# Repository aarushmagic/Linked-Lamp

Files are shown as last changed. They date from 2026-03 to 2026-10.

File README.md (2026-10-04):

<p align="center">
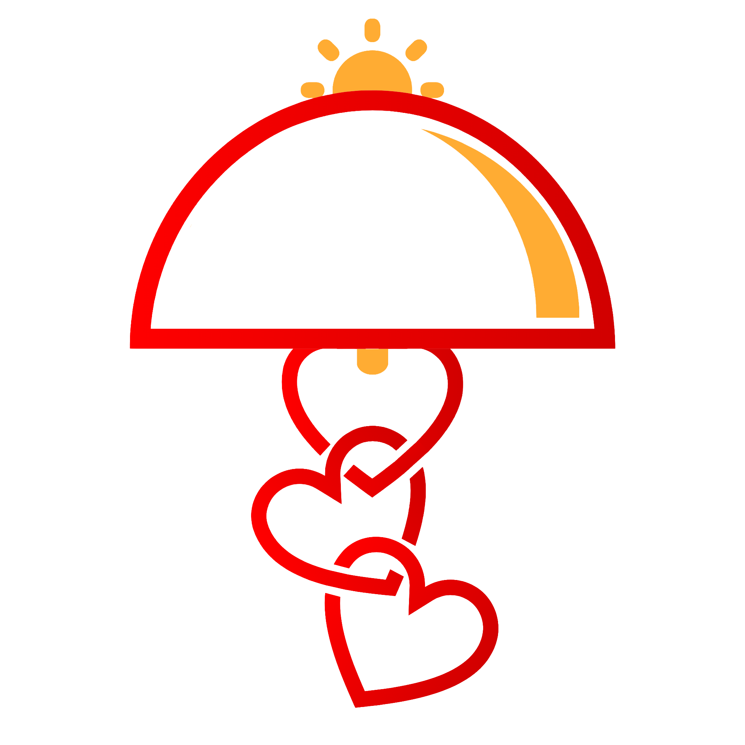
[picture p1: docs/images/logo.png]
Linked Lamp
  
</p>

<h1 align="center">Linked Lamp</h1>

<p align="center">
  An open-source Wi-Fi connected <strong>Friendship Lamp</strong>.<br>
  Tap your lamp to let someone know you're thinking of them — their lamp lights up in your chosen color, anywhere in the world. 
</p>

<p align="center">
  <a href="https://linkedlamp.com">Website</a> · <a href="https://linkedlamp.com/setup.html">Setup Guide</a> · <a href="https://linkedlamp.com/faq.html">FAQ</a>
</p>

---

## ✨ Features

- **Touch Gestures** — Tap to send, double-tap to turn off, hold to pick a new color
- **Breathing Glow** — 20-second pulsing animation (sine wave, ~2s cycle) when a signal arrives, then steady light
- **Smooth Color Transitions** — 5-second gradual fade from current color to new color on every signal
- **Send Confirmation Flash** — Single tap briefly flashes your sent color for 1 second, then reverts
- **Color Pick Confirmation** — After hold-release color selection, lamp flashes the picked color for 3 seconds
- **Color Cycle Presets** — Send multi-color animated sequences from the web app with configurable hold and transition times
- **Virtual Bonfire Mode** — Share a synchronized, organic flickering campfire with your partner from the web app, stoked by adding logs
- **Customizable** — Set your default color, lamp-on duration (1–30 min), and max brightness
- **Nighttime Mode** — Schedule quiet hours with timezone-aware NTP-based timing; reduce brightness or keep the lamp fully off
- **Web App** — Send signals, manage presets, adjust settings, and check for updates from your phone
- **Preset Signals** — Quick-send "I Love You", "I Miss You", or custom messages
- **Ambient Mode** — Optional low-power glow (10% of daytime brightness) in your chosen color or animated effect when the lamp is inactive
- **OTA Updates** — Firmware updates pushed wirelessly with automatic rollback protection (firmware is only marked valid after MQTT connects)
- **Multi-Broker Support** — Works with EMQX, HiveMQ, Eclipse Mosquitto, and any TLS-capable MQTT broker
- **Resilient Connectivity** — Auto-reconnects WiFi and MQTT; reboots after 5 minutes of WiFi failure; retries MQTT every 5 seconds with escalating recovery strategies

## 🔧 Hardware Options

You'll need an **ESP32-WROOM** dev board, a **TTP223** touch sensor, and a 3D-printed enclosure. Then choose one of two lighting methods:

| | PCB | NeoPixel |
|---|---|---|
| **Light Source** | 6× Common Anode RGB LEDs on a custom PCB | WS2812B NeoPixel Ring (up to 16 LEDs, 66mm) |
| **Soldering** | Through-hole components onto PCB | 3 wires to the ESP32 |
| **Brightness** | Standard | Slightly brighter |

Both options produce nearly identical lamps. Any Linked Lamp can connect to any other Linked Lamp regardless of which method was used.

### Wiring

| Signal | GPIO |
|---|---|
| Touch Sensor (TTP223 IO) | 4 |
| **PCB** — Red / Green / Blue channels | 13 / 14 / 27 |
| **NeoPixel** — Data IN | 27 |

Schematics and PCB Gerber files are in `Circuit/`. 3D-printable enclosure files are in `3D Models/`.

## 🚀 Setup

### Browser-Based Setup (Recommended)

The [Setup Guide](https://linkedlamp.com/setup.html) walks you through the entire process:

1. **Parts** — Choose PCB or NeoPixel, download 3D files, and gather components
2. **Assembly** — Solder, wire, and assemble the lamp (takes less than 30 minutes)
3. **Software** — Flash firmware from your browser (Chrome/Edge) or via PlatformIO

### PlatformIO (Advanced)

For developers who want to modify the firmware or use a custom MQTT broker:

1. Install [VS Code](https://code.visualstudio.com/) + [PlatformIO](https://platformio.org/)
2. Open `firmware/pcb/` or `firmware/neopixel/` depending on your hardware
3. Copy `data/config.example.json` → `data/config.json` and fill in your details:
   ```json
   {
     "device_id": "A",
     "mqtt_server": "your-broker.someMQTTBroker.com",
     "mqtt_port": 8883,
     "mqtt_user": "your_username",
     "mqtt_pass": "your_password",
     "delimeter": "/",
     "ota_url": "https://www.linkedlamp.com",
     "owner_name": "Your Name"
   }
   ```
   Set `device_id` to `"A"` for the first lamp and `"B"` for the second. Use the same broker credentials for both.
4. **Upload Filesystem Image** (PlatformIO sidebar → esp32dev → Platform) to push config
5. **Upload** (→ arrow in the bottom bar) to flash firmware
6. Repeat for the second lamp with `device_id` set to `"B"`

### First Boot

On first power-up, the lamp creates a Wi-Fi network called **"Linked Lamp Setup"**. Connect from your phone, select your home network, and enter the password. The lamp will remember it across restarts.

### Web App

The Setup Guide generates personalized Web App UIDs for each lamp. Each person gets a unique token that connects them to the right lamp. You may also choose to save the website as a progressive web app (PWA) on your phone for easier access.
```
https://www.linkedlamp.com/my
```

After the first visit, credentials are saved — you can just open the page normally.

## 📱 How to Use

| Action | What Happens |
|---|---|
| **Single Tap** | Sends your default color to the other lamp. Flashes the sent color for 1 second as confirmation. |
| **Double Tap** | Turns off your lamp (if it's on). If Virtual Bonfire mode is active, extinguishes the fire for both lamps. |
| **5+ Taps** | Resets WiFi settings (only works when lamp is off). Flashes red before restarting. |
| **Hold 1.5s+** | Cycles through all colors (~6 seconds per full rotation). Lift your finger to pick — the lamp flashes your selection for 3 seconds, then saves it as your new default. |

## 🔄 Pushing OTA Firmware Updates (For Maintainers)

1. Compile in PlatformIO — binary outputs to `firmware/[type]/.pio/build/esp32dev/firmware.bin`
2. Run `python docs/flash/build_template.py` to copy binaries
3. Commit and push to GitHub — GitHub Pages hosts the update files
4. Users can trigger an update on-demand by tapping "Check for Update" in the web app.

The ESP32 automatically rolls back if new firmware crashes before reaching `setup()`.

## 📜 License

GNU General Public License v3.0 — see [LICENSE](https://www.gnu.org/licenses/gpl-3.0.html).

## 🙏 Credits

[WiFiManager](https://github.com/tzapu/WiFiManager) · [PubSubClient](https://github.com/knolleary/pubsubclient) · [ArduinoJson](https://github.com/bblanchon/ArduinoJson) · [iro.js](https://iro.js.org/) · [MQTT.js](https://github.com/mqttjs/MQTT.js) · [esptool-js](https://github.com/espressif/esptool-js)

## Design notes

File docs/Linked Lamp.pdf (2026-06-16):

# First Time Setup

1.Plug in the lamp using a USB-C cable and a 5V power adapter
2.Connect your phone to the "Linked Lamp Setup" WiFi network.
3.A configuration page will open automatically. If not, go to http://192.168.4.1 in a browser. 4.Select your home Wi-Fi network, enter the password, and tap Save. The lamp will restart and blink twice to indicate it is connected to WiFI. a.Note: Only 2.4GHz WiFi networks are supported
5.Open the Linked Lamp Dashboard (www.linkedlamp.com/my) and enter your Unique ID (UID) found at the end of this manual
6.If prompted, follow the on-screen steps to install the dashboard as a Progressive Web App (PWA) for ease of use.

# Using the Lamp

1.Single Tap: Sends your color to your partner’s lamp (your lamp will flash briefly to confirm).
2.Tap & Hold: Cycles through colors. Release at any color to save it as your new default.
3.Double Tap: Turns the lamp off (does not affect ambient mode light).
4.Quickly Tap 5+ Times: Resets Wi-Fi settings (confirmed by two red flashes). Then repeat setup steps 2–4.

# LED Indicators

Double green flash: WiFi connected successfully. Double red flash: WiFi credentials are being reset (triggered by 5+ taps). The lamp restarts with the setup hotspot.
1-second color flash: Send confirmation. After a single tap, the lamp briefly shows the color you sent 3-second color flash: Color pick confirmation. After holding to select a new default color, the lamp shows your selection for 3 seconds.
20-second breathing pulse: Signal received. The lamp gently pulses for 20 seconds, then holds a steady glow until the timer expires.

# Firmware Updates

Check for updates manually in the dashboard under Settings > Check for Update. The lamp does not check for or install updates automatically.

Updates are downloaded over Wi-Fi and applied automatically, after which the lamp will reboot.

While automatic crash-recovery is built-in, updates are not guaranteed to be bug-free. Review the source code at www.github.com/aarushmagic/Linked-Lamp before updating.

# My Dashboard

The Web App dashboard is your remote control. Open it in any browser at www.linkedlamp.com/my. Once you enter your Unique ID (UID), your lamp is linked!

# Send Tab

View online/offline status in the top-right corner. Click the icon for details on each individual lamp. Press

"Send Signal" to send your default color to your partner.
“Signal Sending

"
means the signal has left your device.
"Signal Sent"
means the partner

'

s lamp has
received the signal and turned on. Create

"Quick Signals

" (presets) using a single color or a custom color cycle of up to 10 colors.
View the timestamp of the last signal received from your partner.

# Settings Tab

My Default Color: Pick the color sent to your partner when you physically tap the lamp or send tap using the dashboard.
Daytime: Customize the lamp

'

s behavior during
normal hours.
Lamp On Time: Adjust how long your lamp stays lit upon receiving a tap
Max Brightness: Set the daytime light intensity

Ambient Mode: Toggle a low-power background glow in your choice of color when the lamp is idle. Nighttime Mode: Enable a customized schedule to change the lamp

'

s behavior during quiet hours. Schedule & Timezone: Choose your timezone and set the night start/end times.
Night Behavior: Adjust the lamp-on duration and lower the brightness (set to 0% to keep the lamp completely off).
Note: Ambient lighting automatically turns off when Nighttime mode is active.
Check for Update: Manually check for and install the latest wireless firmware updates.
Switch Accounts: Link and switch between multiple lamp profiles on the same device.
Available only when installed as an app/PWA To add multiple accounts, select “Switch Accounts

” in the dashboard and type in the UID of the new lamp.

# Secondary Lamp

Each user is allowed to add one secondary lamp to their account. Visit www.linkedlamp.com/setup-software and simply flash a new lamp using the exact same configurations as your original. The new lamp will automatically detect the primary device and register itself as secondary. Once linked, both lamps will receive incoming signals in sync, and tapping either lamp will send a signal to your partner.

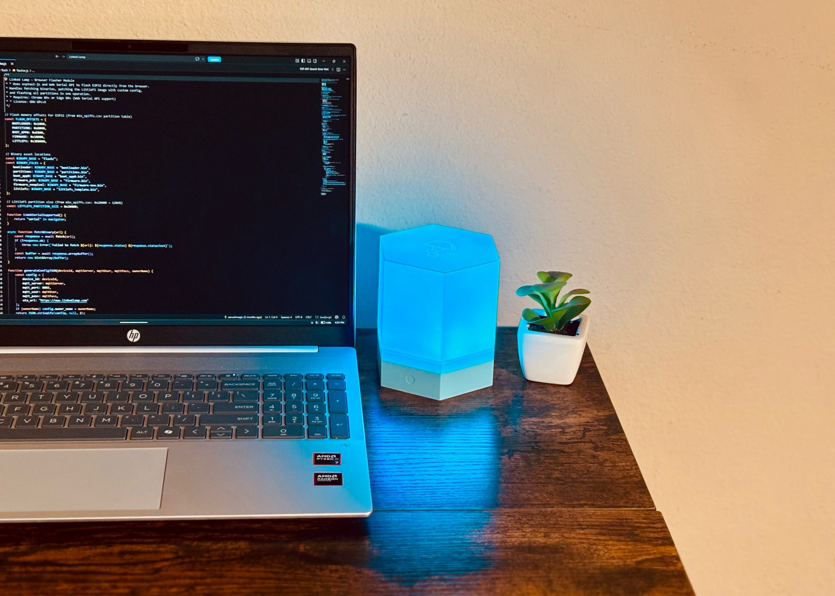
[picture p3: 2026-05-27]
docs/images/blue_lamp.jpg

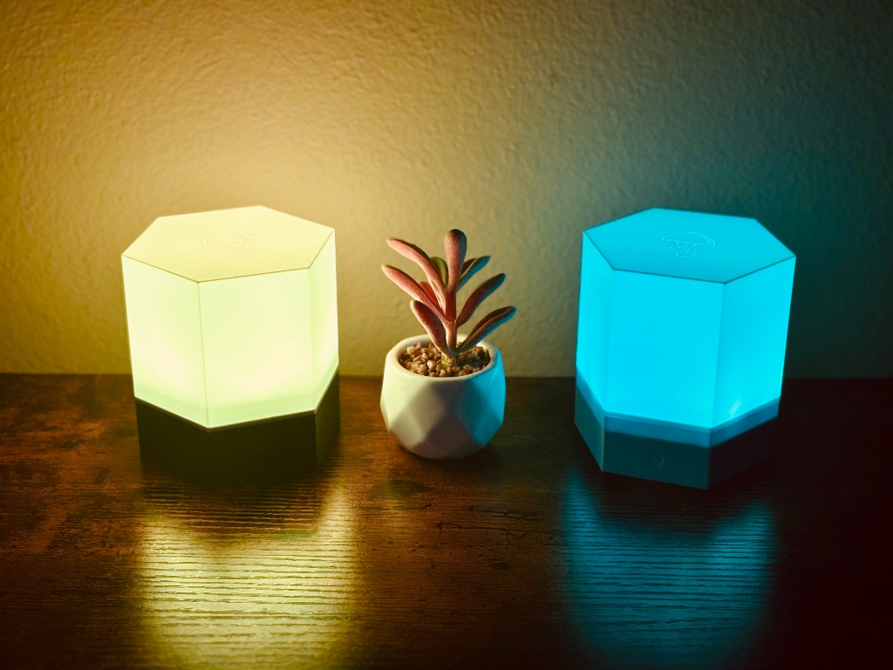
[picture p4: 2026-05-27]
docs/images/lamps_hero.jpg

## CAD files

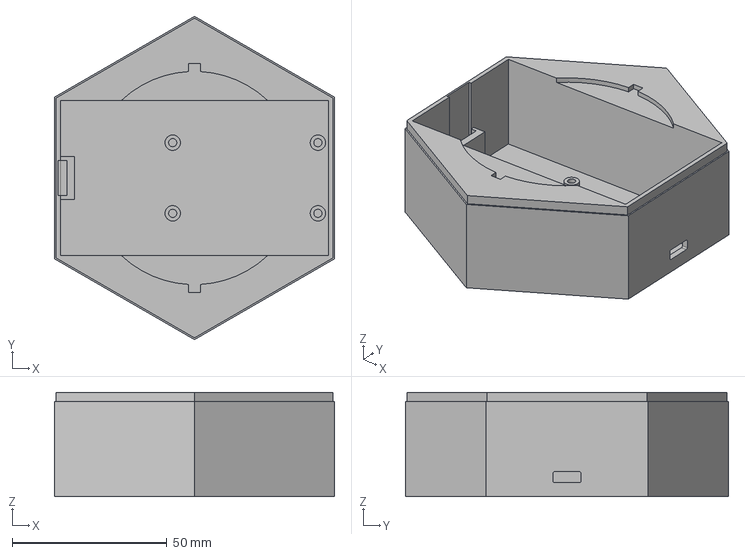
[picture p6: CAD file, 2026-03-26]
3D Models/Neopixel Lamp - 67mm Ring/Neopixel Lamp - Base (M2.5).step
90.6 x 104.6 x 33.8 mm

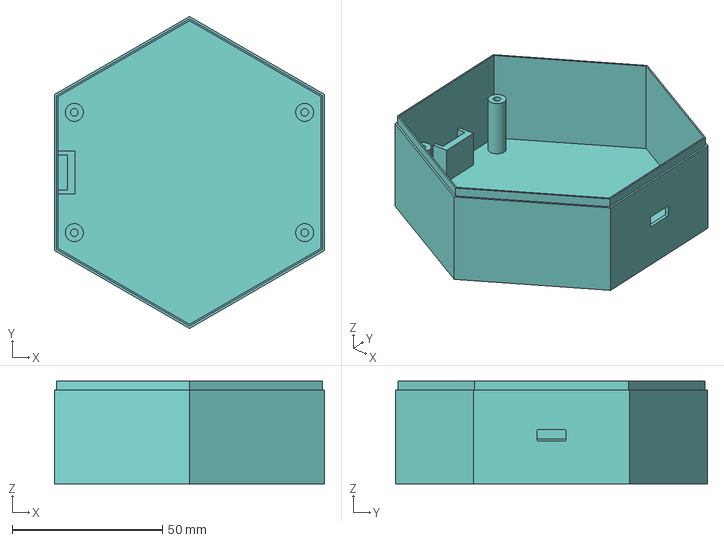
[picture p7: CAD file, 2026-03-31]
3D Models/PCB Lamp - 100mm Hexagon/PCB Lamp 100mm - Base (M2.5).step
89.9 x 103.8 x 34.2 mm

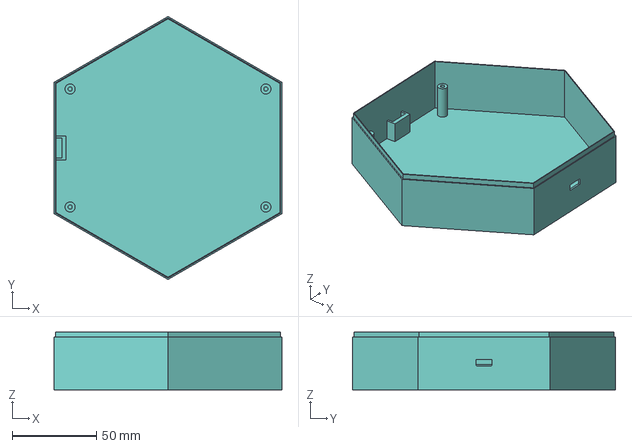
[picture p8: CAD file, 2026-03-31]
3D Models/PCB Lamp - 6in Hexagon/PCB Lamp 6in - Base (M2.5).step
134.8 x 155.7 x 34.2 mm

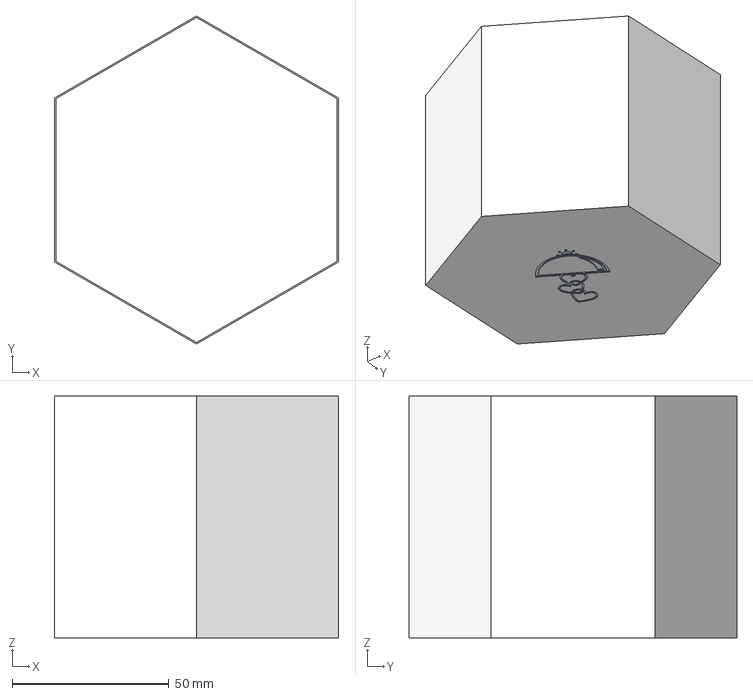
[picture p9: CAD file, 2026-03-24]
3D Models/Neopixel Lamp - 67mm Ring/Neopixel Lamp - 3in Diffuser.step
90.6 x 104.6 x 77.2 mm

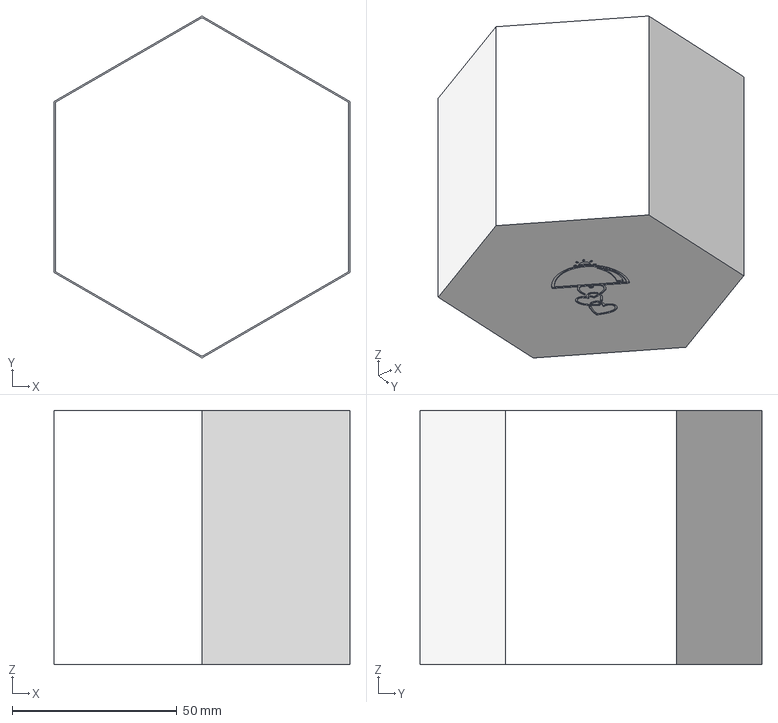
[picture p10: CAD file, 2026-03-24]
3D Models/PCB Lamp - 100mm Hexagon/PCB Lamp 100mm - 3in Diffuser.step
89.8 x 103.7 x 77.2 mm

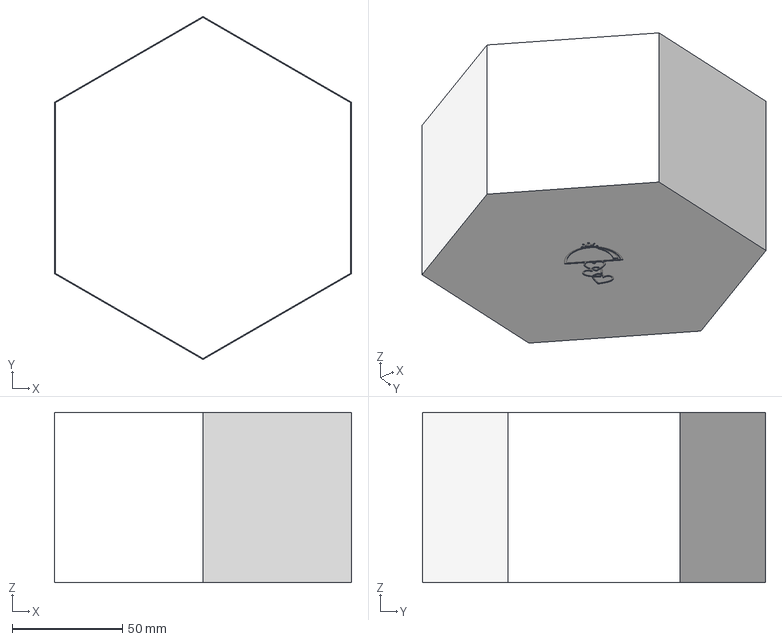
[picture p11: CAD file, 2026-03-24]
3D Models/PCB Lamp - 6in Hexagon/PCB Lamp 6in - 3in Diffuser.step
134.8 x 155.7 x 77.2 mm

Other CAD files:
3D Models/Neopixel Lamp - 67mm Ring/Neopixel Lamp - Base (Spokes).step

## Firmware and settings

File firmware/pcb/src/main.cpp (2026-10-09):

/**
 * Linked Lamp Firmware - Transistor / PCB Version
 * 
 * Controls an ESP32-based friendship lamp using discrete NPN transistors
 * to drive 7 common anode RGB LEDs, a TTP223 touch sensor, and MQTT sync.
 * 
 * Core Hardware:
 *   - ESP32-WROOM
 *   - TTP223 Touch Sensor (Active HIGH, Pin 4)
 *   - 3 NPN Transistors driving common anode RGB LEDs (Pins 13, 14, 27)
 * 
 * Core Features:
 *   - Non-blocking MQTT communication via WebSockets
 *   - Capacitive touch state machine (single tap to send, double tap to turn off, hold to cycle colors)
 *   - Dual-core execution (main loop on Core 1, serial command listener on Core 0)
 *   - Ambient lighting (solid or animated) and timezone-aware nighttime modes
 *   - Over-the-Air (OTA) self-updates with rollback protection
 * 
 * License: GNU GPLv3
 */

#include <Arduino.h>
#include <WiFi.h>
#include <WiFiManager.h>
#include <PubSubClient.h>
#include <HTTPClient.h>
#include <WiFiClientSecure.h>
#include <Update.h>
#include <LittleFS.h>
#include <ArduinoJson.h>
#include <lwip/dns.h>
#include <esp_ota_ops.h>
#include <time.h>
#include "version.h"

// =============================================================================
// Hardware Type Definition
// =============================================================================
#define HW_TYPE "pcb"

// =============================================================================
// Pin Definitions
// =============================================================================
#define TOUCH_SENSOR_PIN 4   // Touch sensor input (Active HIGH)
#define RED_PWM_PIN      13  // Red LED channel PWM pin
#define GREEN_PWM_PIN    14  // Green LED channel PWM pin
#define BLUE_PWM_PIN     27  // Blue LED channel PWM pin

// =============================================================================
// Config values persisted in LittleFS
// =============================================================================
String device_id      = "A";
String target_id      = "B";
String mqtt_server    = "";
int    mqtt_port      = 8883;
String mqtt_user      = "";
String mqtt_pass      = "";
String mqtt_delimiter = "/";
String ota_url        = "https://www.linkedlamp.com";  // Base URL for authorized OTA firmware check
String owner_name     = "";  // Device owner name

// Device role for status mapping
String role = "";
bool   isSupplementary = false;
volatile bool isRebooting = false;
volatile bool pauseCore1 = false;

// Epoch timestamp of the last tap
unsigned long lastTapTimestamp = 0;
bool isFirmwareUpdated = false;

// =============================================================================
// Web-synced settings persisted in LittleFS
// =============================================================================
String defaultColor          = "#FF0000";
int    lampOnTimeMinutes     = 5;       // Day mode active duration (min)
int    dayMaxBrightness      = 255;     // 0-255
bool   nightModeEnabled      = false;
String nightStartTime        = "22:00";
String nightEndTime          = "08:00";
int    nightLampOnTimeMinutes = 5;
int    nightMaxBrightness    = 128;
String userTimezone          = "EST5EDT"; // POSIX timezone format
bool   ambientModeEnabled    = false;
String ambientColor          = "#0000FF";

// =============================================================================
// Ambient Lighting Modes
// =============================================================================
enum AmbientEffect {
  AMBIENT_SOLID,
  AMBIENT_FIRE,
  AMBIENT_BREATH,
  AMBIENT_LAVA,
  AMBIENT_RAIN,
  AMBIENT_AURORA
};
AmbientEffect currentAmbientEffect = AMBIENT_SOLID;

// Cached parsed solid color
uint8_t ambSolidR = 0, ambSolidG = 0, ambSolidB = 255;

// Last calculated ambient output (normalized linear, brightness applied, before gamma)
// Used as the starting point for cross-fading when an active signal arrives
float lastAmbOutR = 0.0f, lastAmbOutG = 0.0f, lastAmbOutB = 0.0f;

// Volatile animation state (kept strictly in RAM, never committed to flash)
unsigned long lastAmbientFrameMs = 0;
float         breathPhase        = 0.0f;
unsigned long nextRainFlareMs    = 0;
unsigned long rainFlareStartMs   = 0;
const unsigned long AMBIENT_FRAME_MS = 20; // ~50 fps update rate

// =============================================================================
// Application state and timing trackers
// =============================================================================
bool           isLampOn           = false;
unsigned long  lampOnStartTime    = 0;
unsigned long  lampDurationMs     = 300000UL; // Day mode active duration in ms
bool           isPulsing          = false;
unsigned long  pulseStartTime     = 0;
const unsigned long PULSE_DURATION_MS = 20000; // Pulse duration in ms

// Pre-scaled output color state
uint8_t currentR = 0, currentG = 0, currentB = 0;
int     currentMaxBrightness = 255;

// Hardware LEDC PWM configuration
const int redChannel    = 0;
const int greenChannel  = 1;
const int blueChannel   = 2;
const int pwmFreq       = 5000;
const int pwmResolution = 13;
const uint32_t PWM_MAX  = 8191; // 2^13 - 1

// Display Color Profile: Standard sRGB Transfer Function (IEC 61966-2-1)
// Calibrated to match the perceptual color curve of iOS and Android phone screens
inline float srgbToLinear(float c) {
  if (c <= 0.0001f) return 0.0f;
  if (c >= 1.0f)    return 1.0f;
  if (c <= 0.04045f) {
    return c / 12.92f;
  }
  return powf((c + 0.055f) / 1.055f, 2.4f);
}

// Ambient mode intensity ratio (calibrated ~4-5% dimmer to achieve subtle background glow)
const float AMBIENT_RATIO = 0.35f;

// Breathing pulse modulation: balanced 50% to 100% perceived brightness
const float PULSE_MIN_FACTOR = 0.50f;
const float PULSE_DEPTH      = 0.50f;

// Hardware PWM Helper (Compatible with ESP32 Arduino Core 2.x and 3.x)
#if defined(ESP_ARDUINO_VERSION_MAJOR) && (ESP_ARDUINO_VERSION_MAJOR >= 3)
  inline void initPwmPin(uint8_t pin, uint32_t freq, uint8_t resolution, uint8_t channel) {
    ledcAttachChannel(pin, freq, resolution, channel);
  }
  inline void writePwmDuty(uint8_t pin, uint8_t channel, uint32_t duty) {
    ledcWrite(pin, duty);
  }
#else
  inline void initPwmPin(uint8_t pin, uint32_t freq, uint8_t resolution, uint8_t channel) {
    ledcSetup(channel, freq, resolution);
    ledcAttachPin(pin, channel);
  }
  inline void writePwmDuty(uint8_t pin, uint8_t channel, uint32_t duty) {
    ledcWrite(channel, duty);
  }
#endif

// Touch sensor gesture state machine
unsigned long lastTouchTime     = 0;
unsigned long touchStartTime    = 0;
int           tapCount          = 0;
bool          isTouching        = false;
bool          wasTouching       = false;
const unsigned long TAP_TIMEOUT = 400; // Multi-tap window (ms)
bool          longPressTriggered = false;

// Color wheel spectrum cycle state
float hue              = 0.0;
bool  isCyclingColors  = false;
unsigned long cycleStartTimeMs = 0;
float cycleStartHue = 0.0;
const float CYCLE_PERIOD_MS = 6000.0; // Color cycle period (ms)

// Color transition crossfade state
bool isTransitioning = false;
unsigned long transitionStartMs = 0;
const unsigned long TRANSITION_DURATION = 5000; // Transition duration (ms)
uint8_t transFromR = 0, transFromG = 0, transFromB = 0;
uint8_t transToR = 0, transToG = 0, transToB = 0;

// Custom multi-color pattern cycle state
struct CycleEntry {
  uint8_t r, g, b;
  unsigned long holdMs;
  unsigned long transMs;
};
const int MAX_CYCLE_ENTRIES = 50;
CycleEntry cycleEntries[MAX_CYCLE_ENTRIES];
int cycleEntryCount = 0;
int cycleCurrentIndex = 0;
bool isColorCycling = false;
unsigned long cycleStepStartMs = 0;
enum CyclePhase { CYCLE_HOLD, CYCLE_TRANSITION };
CyclePhase cyclePhase = CYCLE_HOLD;

// Feedback flash state for tap transmissions
bool isSendFlashing = false;
unsigned long sendFlashStart = 0;
const unsigned long SEND_FLASH_DURATION = 1000; // Confirmation flash duration (ms)
uint8_t preSendR = 0, preSendG = 0, preSendB = 0;
bool wasLampOnBeforeSend = false;

// Feedback flash state for color selection
bool isColorPickFlashing = false;
unsigned long colorPickFlashStart = 0;
const unsigned long COLOR_PICK_FLASH_DURATION = 3000; // Pick confirmation flash duration (ms)
uint8_t prePickR = 0, prePickG = 0, prePickB = 0;
bool wasLampOnBeforePick = false;

// =============================================================================
// WiFi networking state
// =============================================================================
WiFiManager     wifiManager;
WiFiClientSecure espClientSecure;
PubSubClient    mqttClient(espClientSecure);

bool           wifiConnected            = false;
bool           hasConnectedOnce         = false;
unsigned long  lastWifiReconnectAttempt  = 0;
const unsigned long WIFI_RECONNECT_INTERVAL = 15000;
unsigned long  wifiDisconnectedSince    = 0;
const unsigned long WIFI_RESTART_TIMEOUT  = 300000; // Reboot threshold (ms) on connection loss

// Persistent RTC memory (survives soft resets)
RTC_NOINIT_ATTR uint32_t rtcBootMarker;
RTC_NOINIT_ATTR bool rtcLastKnownIsNight;
RTC_NOINIT_ATTR bool rtcBonfireActive;
RTC_NOINIT_ATTR uint64_t rtcLastBonfireLogEpoch;
const uint32_t BOOT_MARKER_VALUE = 0xCAFEBEEF;
bool isColdBoot = false;

// =============================================================================
// Virtual Bonfire State (Co-Presence Glow) - Zero Flash Writes
// =============================================================================
bool          isBonfireActive     = false;
uint64_t      lastBonfireLogEpoch = 0;
uint64_t      flareStartEpoch     = 0;
bool          isBonfireFlaring    = false;

// MQTT connection state
unsigned long  lastMqttReconnectAttempt = 0;
const unsigned long MQTT_RECONNECT_INTERVAL = 5000;
int            mqttFailCount = 0;

// Periodic status maintenance
unsigned long  lastStatusCheck = 0;
const unsigned long STATUS_CHECK_INTERVAL = 300000; // 5 minutes
bool           selfStatusOnline = false; // Tracks reported online status

// Retained MQTT state refresher
unsigned long lastDailyRefresh = 0;
const unsigned long DAILY_REFRESH_INTERVAL = 86400000UL; // Daily refresh interval (ms)

// Dynamically generated MQTT topics
String triggerTopicSub;
String triggerTopicPub;
String settingsTopicSub;
String statusTopicPub;
String partnerStatusTopicSub;    // Subscribes to partner primary status
String partnerSupStatusTopicSub; // Subscribes to partner secondary status
String bonfireTopicSub;          // Retained bonfire state topic
String bonfireTopicPub;          // Partner bonfire state topic

// =============================================================================
// Function Prototypes
// =============================================================================
void loadConfig();
void loadState();
void saveState();
void setupPins();
void setupMQTT();
void onWifiConnect();
void handleWifi();
void handleMqttReconnect();
void handleTouch();
void doActionBasedOnTaps();
void handleLEDs();
void mqttCallback(char* topic, byte* payload, unsigned int length);
void parseSettings(String payload);
void setColor(String hexColor);
void setRGB(uint8_t r, uint8_t g, uint8_t b);
void setRGBFloat(float rLin, float gLin, float bLin);
void setRGBDuty(uint32_t dutyR, uint32_t dutyG, uint32_t dutyB);
uint32_t applyGamma13(float linearIntensity);
bool isAuthorizedOTAUrl(const String& urlStr);
void performOTA(String url);
float hexToHue(String hexColor);
bool isNighttime();
void publishSettingsViaMQTT();
void startColorTransition(uint8_t toR, uint8_t toG, uint8_t toB);
void parseColorCycle(String payload);
void serialCommandTask(void *pvParameters);
void processSerialCommand(String cmd);
void detectRole();
uint64_t getEpochMs();
void startBonfire(uint64_t logEpoch, bool publishMqtt);
void addBonfireLog(bool publishMqtt);
void extinguishBonfire(bool publishMqtt, const char* reason);
void renderBonfireFrame(uint64_t epochMs);
void resolveAmbientEffect();
void renderAmbientFrame();
void writeAmbientOutput(float rLin, float gLin, float bLin);
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
void loop() {
  if (pauseCore1) { delay(10); return; }
  if (isRebooting) return;
  wifiManager.process();
  handleWifi();
  handleTouch();
  handleLEDs();
}

// =============================================================================
// WiFi Networking and Maintenance
// =============================================================================
void onWifiConnect() {
  wifiConnected = true;
  mqttFailCount = 0;

  Serial.println("WiFi Connected!");
  Serial.print("IP Address: ");
  Serial.println(WiFi.localIP());

  // Override default DNS with public servers
  ip_addr_t dns1, dns2;
  IP4_ADDR(&dns1.u_addr.ip4, 8, 8, 8, 8);
  dns1.type = IPADDR_TYPE_V4;
  IP4_ADDR(&dns2.u_addr.ip4, 1, 1, 1, 1);
  dns2.type = IPADDR_TYPE_V4;
  dns_setserver(0, &dns1);
  dns_setserver(1, &dns2);
  Serial.println("Public DNS set: 8.8.8.8 / 1.1.1.1");

  // Pulse green to confirm local connection
  if (!hasConnectedOnce && isColdBoot) {
    hasConnectedOnce = true;
    
    setRGB(0, 120, 0);
    delay(200);
    setRGB(0, 0, 0);
    delay(200);
    setRGB(0, 0, 0);
    delay(200);
    setRGB(0, 120, 0);
    delay(200);
    setRGB(0, 0, 0);
  }

  // Sync time against configured timezone
  configTzTime(userTimezone.c_str(), "pool.ntp.org", "time.nist.gov", "time.google.com");
}

void handleWifi() {
  if (WiFi.status() == WL_CONNECTED) {
    if (!wifiConnected) {
      onWifiConnect();
    }

    // Maintain non-blocking MQTT client state
    if (!mqttClient.connected()) {
      handleMqttReconnect();
    } else {
      mqttClient.loop();

      // Correct reported status if retained state is inconsistent
      if (millis() - lastStatusCheck >= STATUS_CHECK_INTERVAL) {
        lastStatusCheck = millis();
        if (!selfStatusOnline) {
          String onlineMsg = String("ONLINE:") + HW_TYPE;
          mqttClient.publish(statusTopicPub.c_str(), onlineMsg.c_str(), true);
          Serial.println("Status correction: re-published ONLINE (was showing OFFLINE)");
        }
      }

      // Retained MQTT state refresher: Constantly refresh retained messages just in case the broker drops them
      if (millis() - lastDailyRefresh >= DAILY_REFRESH_INTERVAL) {
        lastDailyRefresh = millis();
        
        // Push Status
        String onlineMsg = String("ONLINE:") + HW_TYPE;
        mqttClient.publish(statusTopicPub.c_str(), onlineMsg.c_str(), true);
        
        
        publishSettingsViaMQTT();
        
        Serial.println("24-Hour Refresher: Pushed retained status and settings to MQTT.");
      }
    }
  } else {
    // Handle connection drop and schedule reconnects
    if (wifiConnected) {
      wifiConnected = false;
      wifiDisconnectedSince = millis();
      Serial.println("WiFi lost! Attempting reconnect...");
      WiFi.disconnect();
      WiFi.reconnect();
    }

    // Reset device if connection is lost for more than 5 minutes
    if (wifiDisconnectedSince > 0 && (millis() - wifiDisconnectedSince >= WIFI_RESTART_TIMEOUT)) {
      Serial.println("WiFi disconnected 5 min. Restarting...");
      ESP.restart();
    }

    // Attempt reconnect on configured intervals
    if (millis() - lastWifiReconnectAttempt > WIFI_RECONNECT_INTERVAL) {
      lastWifiReconnectAttempt = millis();
      Serial.println("WiFi reconnect attempt...");
      WiFi.disconnect();
      WiFi.reconnect();
    }
  }
}

// =============================================================================
// Initialization Helpers
// =============================================================================
void setupPins() {
  pinMode(TOUCH_SENSOR_PIN, INPUT); // TTP223: Active HIGH

  initPwmPin(RED_PWM_PIN, pwmFreq, pwmResolution, redChannel);
  initPwmPin(GREEN_PWM_PIN, pwmFreq, pwmResolution, greenChannel);
  initPwmPin(BLUE_PWM_PIN, pwmFreq, pwmResolution, blueChannel);

  setRGB(0, 0, 0);
}

void loadConfig() {
  bool configValid = false;

  if (LittleFS.exists("/config.json")) {
    File f = LittleFS.open("/config.json", "r");
    if (f) {
      JsonDocument doc;
      if (!deserializeJson(doc, f)) {
        device_id      = doc["device_id"]   | "A";
        mqtt_server    = doc["mqtt_server"] | "";
        mqtt_port      = doc["mqtt_port"]   | 8883;
        mqtt_user      = doc["mqtt_user"]   | "";
        mqtt_pass      = doc["mqtt_pass"]   | "";
        mqtt_delimiter = doc["delimeter"]   | "/";
        ota_url        = doc["ota_url"]     | "https://www.linkedlamp.com";
        if (ota_url.length() == 0) ota_url = "https://www.linkedlamp.com";
        owner_name     = doc["owner_name"]  | "";
        if (mqtt_server.length() > 0) {
          configValid = true;
          Serial.println("Config loaded from /config.json");
          Serial.println("MQTT Server: " + mqtt_server);
        }
      }
      f.close();
    }
  }

  // Accept serial configuration if local config is absent
  if (!configValid) {
    Serial.println("SEND_CONFIG");  // Send handshake to web interface
    Serial.println("Waiting for config via Serial (30s timeout)...");
    unsigned long waitStart = millis();
    String serialBuffer = "";

    while (millis() - waitStart < 30000) {
      if (Serial.available()) {
        char c = Serial.read();
        serialBuffer += c;
        if (c == '\n' || c == '\r') {
          serialBuffer.trim();
          if (serialBuffer.startsWith("{") && serialBuffer.endsWith("}")) {
            JsonDocument doc;
            if (!deserializeJson(doc, serialBuffer)) {
              device_id      = doc["device_id"]   | "A";
              mqtt_server    = doc["mqtt_server"] | "";
              mqtt_port      = doc["mqtt_port"]   | 8883;
              mqtt_user      = doc["mqtt_user"]   | "";
              mqtt_pass      = doc["mqtt_pass"]   | "";
              mqtt_delimiter = doc["delimeter"]   | "/";
              ota_url        = doc["ota_url"]     | "https://www.linkedlamp.com";
              if (ota_url.length() == 0) ota_url = "https://www.linkedlamp.com";
              owner_name     = doc["owner_name"]  | "";

              // Persist config to local storage
              if (!LittleFS.begin(true)) { LittleFS.format(); LittleFS.begin(true); }
              File wf = LittleFS.open("/config.json", "w");
              if (wf) {
                serializeJsonPretty(doc, wf);
                wf.close();
              }
              Serial.println("CONFIG_SAVED");
              Serial.println("Config received and saved to /config.json");
              Serial.println("MQTT Server: " + mqtt_server);
              return;
            }
          }
          serialBuffer = "";
        }
      }
      delay(10);
    }
    Serial.println("No config received. Continuing with defaults.");
  }
}

void loadState() {
  if (!LittleFS.exists("/state.json")) return;
  File f = LittleFS.open("/state.json", "r");
  if (!f) return;

  JsonDocument doc;
  if (!deserializeJson(doc, f)) {
    defaultColor          = doc["defaultColor"]   | "#FF0000";
    lampOnTimeMinutes     = doc["dayTimeMin"]     | 5;
    dayMaxBrightness      = doc["dayBright"]      | 255;
    nightModeEnabled      = doc["nightMode"]      | false;
    nightStartTime        = doc["nightStart"]     | "22:00";
    nightEndTime          = doc["nightEnd"]        | "08:00";
    nightLampOnTimeMinutes = doc["nightTimeMin"]   | 5;
    nightMaxBrightness    = doc["nightBright"]     | 128;
    userTimezone          = doc["timezone"]         | "EST5EDT";
    ambientModeEnabled    = doc["ambientMode"]      | false;
    ambientColor          = doc["ambientColor"]     | "#0000FF";
    resolveAmbientEffect();
    lastTapTimestamp      = doc["lastTapTimestamp"] | 0UL;
    if (doc["role"].is<const char*>()) role = doc["role"].as<String>();

    String savedFw = doc["fwVersion"] | "";
    if (savedFw != FIRMWARE_VERSION_STR) {
      isFirmwareUpdated = true;
      Serial.println("Recently updated firmware detected! Old: '" + savedFw + "' -> New: '" + FIRMWARE_VERSION_STR + "'");
    }
    Serial.println("State loaded. Default color: " + defaultColor + ", Role: " + (role.length() > 0 ? role : "unset"));
  }
  f.close();

  if (isFirmwareUpdated) {
    saveState();
  }
}
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

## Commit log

2026-03-12 Remove Sample Files from repository
2026-03-12 Fixed some potential vulnerabilities
    [main.cpp]
2026-03-15 Fixed button and 404 Page
2026-03-15 Attempted fix for OTA updates
    [main.cpp]
2026-03-15 Fixed web flash (Maybe)
    [main.cpp]
2026-03-16 Enabled OTA Update failsafe
    [main.cpp]
2026-03-21 Fixed 0 to color fade
    [main.cpp]
2026-03-24 Added Hardware Files
    [Neopixel Lamp - 3in Diffuser.step, Neopixel Lamp - Base (M3).step, Neopixel Lamp - Base (Spokes).step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]
2026-03-26 Fixed Parts List
    [Neopixel Lamp - Base (M2.5).step, PCB Lamp 100mm - Base (M2.5).step, PCB Lamp 6in - Base (M2.5).step]
2026-03-26 Fixed 3D Models
    [Neopixel Lamp - Base (M2.5).step, PCB Lamp 6in - Base (M2.5).step]
2026-03-27 Included more 3rd Party MQTT Brokers
    [main.cpp]
2026-03-30 Updated to 5 taps to reset
    [main.cpp]
2026-03-31 Updated instructions
    [PCB Lamp 100mm - Base (M2.5).step]
2026-03-31 Fixed screw hole size
    [PCB Lamp 100mm - Base (M2.5).step, PCB Lamp 6in - Base (M2.5).step]
2026-04-05 Fixed online status push
    [main.cpp]
2026-04-08 Attempted fix for notifs
    [main.cpp]
2026-04-09 Attempted notification throttle limiting fix
    [main.cpp]
2026-04-09 Revert out of notifications while still keeping PWA
    [main.cpp]
2026-05-10 Added FAQ on driver installation
2026-05-12 Potential fix to resolve false MQTT commands on role switch
    [main.cpp]
2026-05-13 Using gamma correction for color accuracy fix.
    [main.cpp]
2026-05-14 Color cycling bug fix
    [main.cpp]
2026-05-21 Added UID, PWA instructions and account switching
2026-05-24 Fixed remote code execution vulnerability
    [main.cpp]
2026-06-16 Added a printable/foldable customized PDF user manual
2026-07-15 Fixed message send confirmation
    [main.cpp]
2026-09-16 Added high pwm resolution and more color accurate gamma correction
    [main.cpp]
2026-10-01 Fixed night state retention bug
    [main.cpp]
